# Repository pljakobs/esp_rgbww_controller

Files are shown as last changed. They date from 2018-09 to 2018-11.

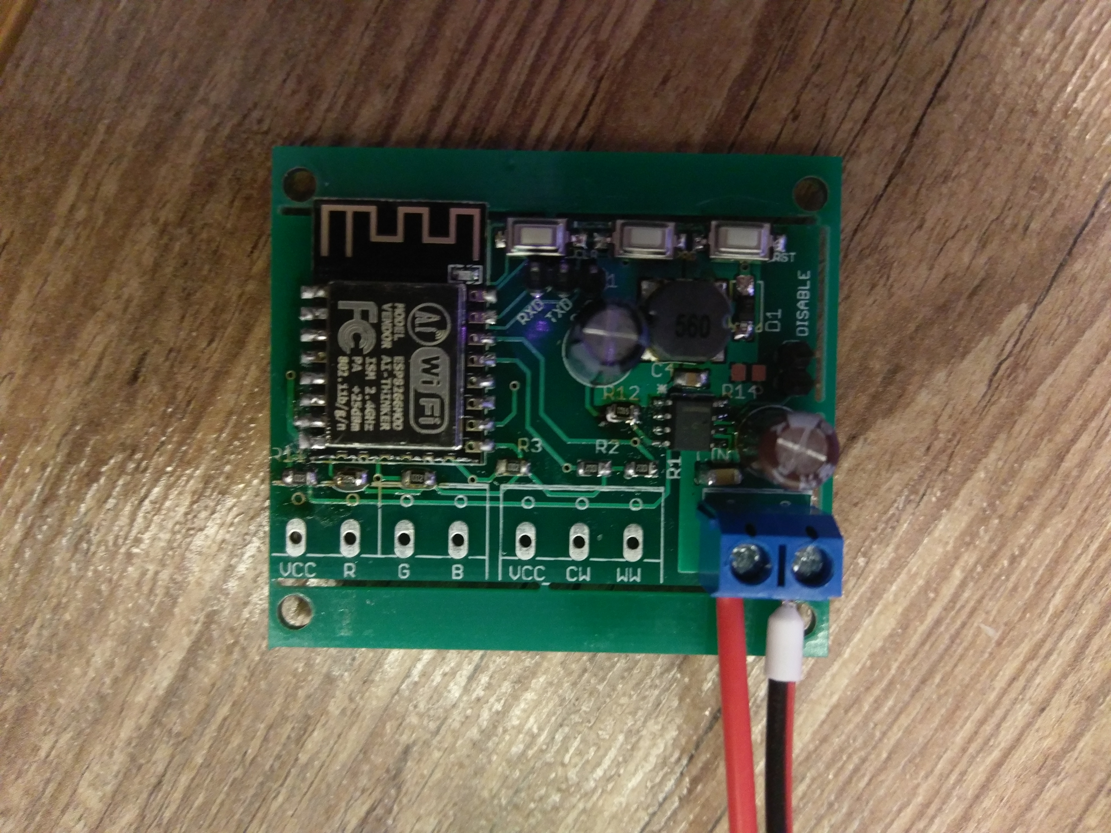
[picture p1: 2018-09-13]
IMAG0143.jpg

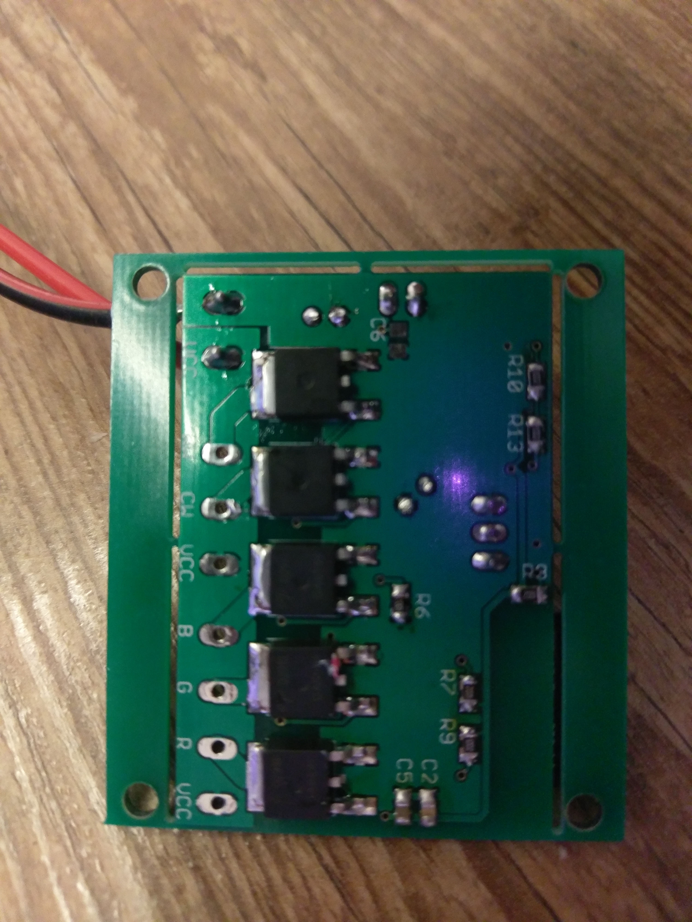
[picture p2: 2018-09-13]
IMAG0144.jpg

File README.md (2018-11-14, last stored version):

View this project on [CADLAB.io](https://cadlab.io/project/1422). 

# ESP8266 WiFi RGBWW LED Dimmer v1.5
Custom Hardware board for controlling 5 Led Channels via PWM (RGB + Warm/Cold White). It is designed for max current ~4.5A per Channel.

# Changelog

* 1.5 (31.01.2017)
  * DCDC wandler has been remeasured and provided for through hole mounting on pin headers
  * Jumper introduced for allowing for external 3,3V connections
  * measurements have been changed to 53mm*47mm with mounting holes tailored towards "Strapubox CO 4" casing
  * C1 has been replaced with a smaller form factor

* 1.3 (20.02.2016)
  * added another tact switch which can be used during boot to reset settings
  * silksceen naming updated 

* 1.2 (16.02.2016)
  * improved the layout for better EMV
  * added buffer capacitor for dc converter
  * added filter capacitor close to ESP8266
  
* 1.1 (01.02.2016)
  * connected ADC 
  * some layout improvements

# Parts
- 1x ESP8266, ESP-12 format
- 1x XM1584 Power converter (set to 3.3v!)
- 5x IRLZ44N Mosfet (logic level gate threshold)
- 11x 10k resistors, 0805 (R1 - R11)
- 1x 1k resistors, 0805 (R12)
- 1x 330 µF Elko RM 2.5 mm (C1) 
- 1x 100 µF Elko RM 2.5 mm (C3)
- 1x 100 nF capacitor 0805(C2)
- 3x 5,08mm 2pin terminal block
- 1x 5,08mm 3pin terminal block
- 1x 2,54mm 4pin header
- 2x Micro SMD Tact Switch 2 pin 3*6*2.5 mm (optional)

# Assembly
Assembly of the PCB Board is straight forward, solder all parts to the PCB.

__Caution :__ before soldering the esp module to the PCB, set the output voltage of XM1584 converter  to 3.3v

### Recommended steps
- Start with soldering the smd resistors
- __Ensure the output voltage of XM1584 converter is 3.3v before continuing__. 
- Solder the XM1584 Power Board 
- Solder ESP8266 Module 
- Optional: solder SMD Tact Switch
- Solder Elkos
- Solder Terminal Blocks, 4pin header 
- Solder FETs

# Firmware
Firmware is still work in progress.

Latest can be found here:
https://github.com/patrickjahns/esp_rgbww_controller_fw

# Modifying
The schematic and board files are compatible with eagle 7.2+

## Ideas
Here are some ideas for future revisions
- see if we can clear some GPIOs and provide them via PIN Header for other enhancements (i.e. IR / Rotary Controller) 
- change layout for VCC/GND to be on the left side
- ~~connect ADC to detect power failure~~ 

# Resources
* [ESP RGB Project](https://github.com/RiRomain/esp-dimmer-hardware)
* [H801 Wifi Controller Hack](http://chaozlabs.blogspot.de/2015/08/esp8266-in-wild-wifi-led-controller-hack.html)

# Thread in Fhem Forum
* [Entwicklung/Sammelbestellung RGBWW Wifi Led Controller](https://forum.fhem.de/index.php/topic,48918.msg)

# Credits
Thanks to RiRomain for his excellent documentated [ESP RGB Project](https://github.com/RiRomain/esp-dimmer-hardware)

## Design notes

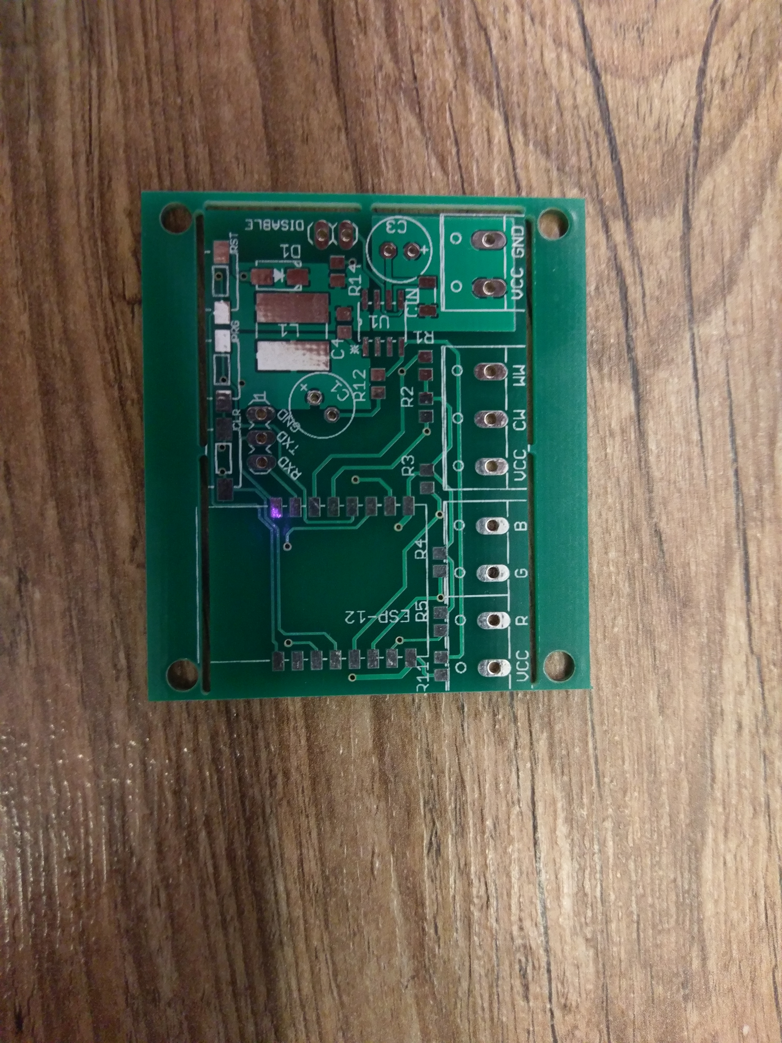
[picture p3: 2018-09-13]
IMAG0142.jpg

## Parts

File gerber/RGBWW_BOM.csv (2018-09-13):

Part | Value | Package
R1-R11, R13 | 10k | R0805
R12 | 5.9k | R0805
C1 | 440nF | E2,5-7
C2 | 100nF | C0805
C3 | 240uF | E2,5-7
C4, C5 | 10nF | C0805
CIN | 4.7uF | 1206
L1 | 56uH | IND_NPI75C
Q1-Q5 | AOD2910SMD | DPAK-3
CLR, PRG, RST | TACTILE-SWITCH-1101NE
D1 | 570mV | SMA
U1 | TPS5410DR | M08A
DISABLE | 1X02 | pinhead
ESP-12 | ESP8266_ESP-12 | ESP8266-ESP12
PROG | MA03-1 | con-lstb
RGB | W237-4P | con-wago-508
VCC | W237-132 | con-wago-508
W | W237-133 | con-wago-508

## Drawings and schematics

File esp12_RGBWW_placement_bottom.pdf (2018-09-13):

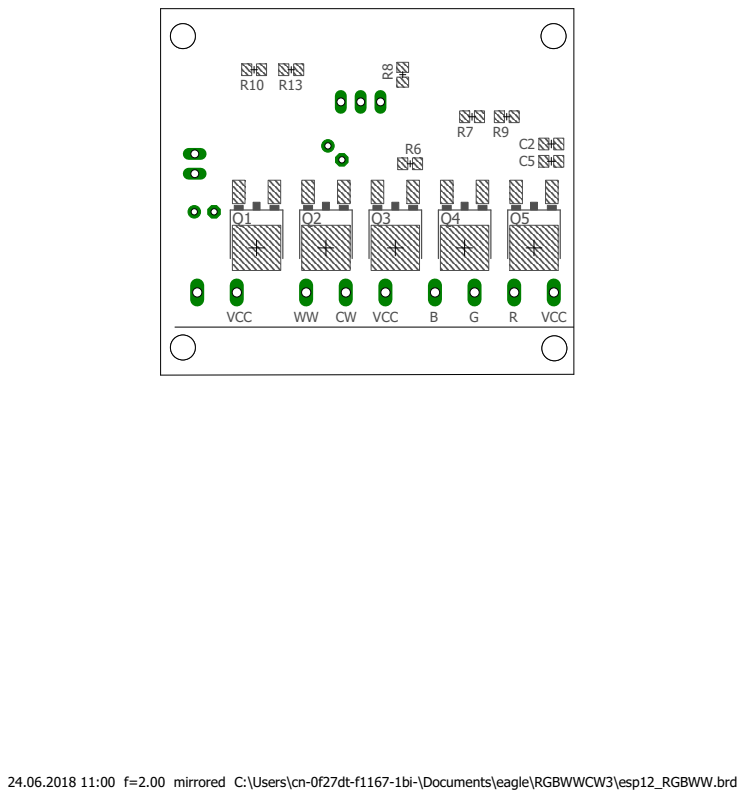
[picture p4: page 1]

24.06.2018 11:00 f=2.00 mirrored C:\Users\cn-0f27dt-f1167-1bi-\Documents\eagle\RGBWWCW3\esp12_RGBWW.brd

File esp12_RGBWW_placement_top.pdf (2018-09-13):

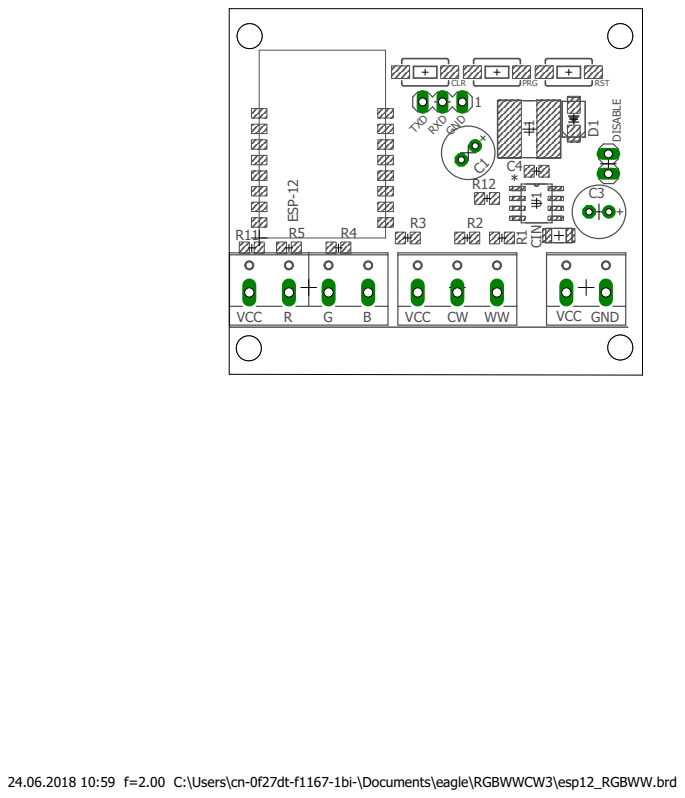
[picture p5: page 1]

24.06.2018 10:59 f=2.00 C:\Users\cn-0f27dt-f1167-1bi-\Documents\eagle\RGBWWCW3\esp12_RGBWW.brd

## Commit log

2017-10-04 new, smaller board
    new design, integrated DCDC converter, new, smaller MOSFETs, smaller overal board, additional PRG button, mostly optimized for SMD manufacturing but still hand solderable
    [esp12_RGBWW.brd, esp12_RGBWW.sch]
2017-11-19 minor placement changes
    [esp12_RGBWW.brd, esp12_RGBWW.sch]
2017-11-19 another reduction in size
    replaced most of the power supply parts, shaved off another 3mm
    [esp12_RGBWW.brd]
2018-03-01 updated silk screen
    some minor changes, mostly cleaned up silk screen
    [esp12_RGBWW.GBL, esp12_RGBWW.GBO, esp12_RGBWW.GBP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]
2018-03-01 added BOM
    BOM
2018-04-07 added enable function
    I added a pin header to short the TPS5410's ENABLE pin to GND, thus switching off the DC/DC converter, effectively turning the controller completely off.
    The controller should function normally, when this is left open. Including a switch that connects those two pins is a way of switching the controller off without disconnecting the 12V supply. Whatever it'll be good for.
    [esp12_RGBWW.brd, esp12_RGBWW.sch]
2018-04-11 some power supply improvements
    added a snubber network to PH (140MHz) plus a 10nF cap on the +3V3 line
    Added low impedance floodfills for +3V3 and PH where applicable
    switched the location of the RST and PRG switches since it seems easier to have the RST on the outside
    [esp12_RGBWW.brd, esp12_RGBWW.sch]
2018-04-14 more board improvements
    - floodfills for VCC, PH and top layer +3V3 nods
    - RC snubber for PH node
    - additional 10nF cap close to the ESPs 3.3V
    - cleaned up the GND layer a bit
    [esp12_RGBWW.brd]
2018-05-05 yet more minor changes on the input side
    removed the snubber pads
    created a lower impedance GND path
    swiched RXD and TXD for some more elegant routing and better fit with the usual USB/UART connectors (straight cable now switches RX/TX)
    minor silkscreen corrections for better legibility
    [esp12_RGBWW.brd, esp12_RGBWW.sch]
2018-05-12 updated Gerber Files and Pictures
    exported Gerber Files, shot a few new pictures of the board.
    Unlike the Beta Boards, this version does not have pads for an R/C snubber as I don't think it will be necessary. Also, there's a larger GND area covering the top layer input side of the circuit and 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
    The TXD and RXD pins have switched places, it was easier to route them like that and also, their location now crosses over with the usual USB/UART converters (straight cable run).
    On the disable jumper location, the pins have also switched places, disable is now on the top, pointing away from C3
    [esp12_RGBWW.GBL, esp12_RGBWW.GBO, esp12_RGBWW.GBP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]
2018-05-12 added two dimension measurements
    [esp12_RGBWW.brd]
2018-05-12 cosmetical correction
    beautified the crossing of RXD and TXD
    [esp12_RGBWW.sch]
2018-09-13 minor routing changes
    updated a few minor routings (clr) and added some more copper areas (GND around DISABLE & D1)
    [RGBWW_BOM.csv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]
2025-04-18 commitintg the Lightinator mini design in Eagle format
    [esp12_RGBWW.GBL, esp12_RGBWW.GBO, esp12_RGBWW.GBP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]
